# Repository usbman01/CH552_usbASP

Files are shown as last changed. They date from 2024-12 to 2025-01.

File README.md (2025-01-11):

# CH552_usbASP

A CH552 version of the popular usbasp from fischl. The code is mostly based on version 1.8 of nerdralph https://github.com/nerdralph/usbasp with some minor changes, exept for tpi.c and usbdrv.c which are completely new. It will work on the following WCH microcontroller:

  - CH551 (needs some changes because of XDATA limits)
  - CH552
  - CH554

CH552_usbasp is much more stable because it no longer depends on VUSB. On windows machines it can automatically load winusb as driver so no more installation issues and hassles with zadig. If there is already a usbasp installation on the PC with libusb, libusb will be used. On Linux always libusb will be used because WCID is windows only.

## Features:

  - Fullspeed (12MHz) design
  - Firmware update via USB using WCHs WCHISPTool 
  - Automatic driver installation on Win8.1 and above
  - Winusb driver (tested with avrDude >= 7.1)
  - Compound device with USB CDC-ACM serial port 
  - 5V and 3.3V operation

## Config Options:

WCID, TPI, CDC and the fast copy function can be switched off. For details check global.h The code can be compiled using Keil c51, SDCC or Raisonance rc51. A port to IAR EW8051 is still under develpment and currently not working.   
Since i dont have AVRs using TPI at hand TPI is just simulated and may or may not work. 

## Benchmarks:

Since the code is prepared to work with various C compiler it also can be used for benchmarking popular MCS51 C compiler. 

## Limits:

When using the compound version including CDC its neccessary to use avrdude-v8.0-windows-mingw-x64.zip because the normal version can not handle compount devices.

## todo:

 - make usbdrv usb2cv compilant
 - complete CDC support
 - switch to 24MHz fsys so CDC can work up to 115k2 baud
 - complete SDCC support (build) ✔
 - use that extra opcode for memcpy functions ✔
 - add Raisonance RC51 support ✔
 - complete IAR EW8051 support

## References:

 - Datasheet:  https://www.wch-ic.com/downloads/CH552DS1_PDF.html
 - Isptool:    https://www.wchic.com/downloads/WCHISPTool_Setup_exe.html
 - usbasp 1.4: https://www.fischl.de/usbasp/
 - usbasp 1.8: https://github.com/nerdralph/usbasp
 - avrdude:    https://github.com/avrdudes/avrdude/releases

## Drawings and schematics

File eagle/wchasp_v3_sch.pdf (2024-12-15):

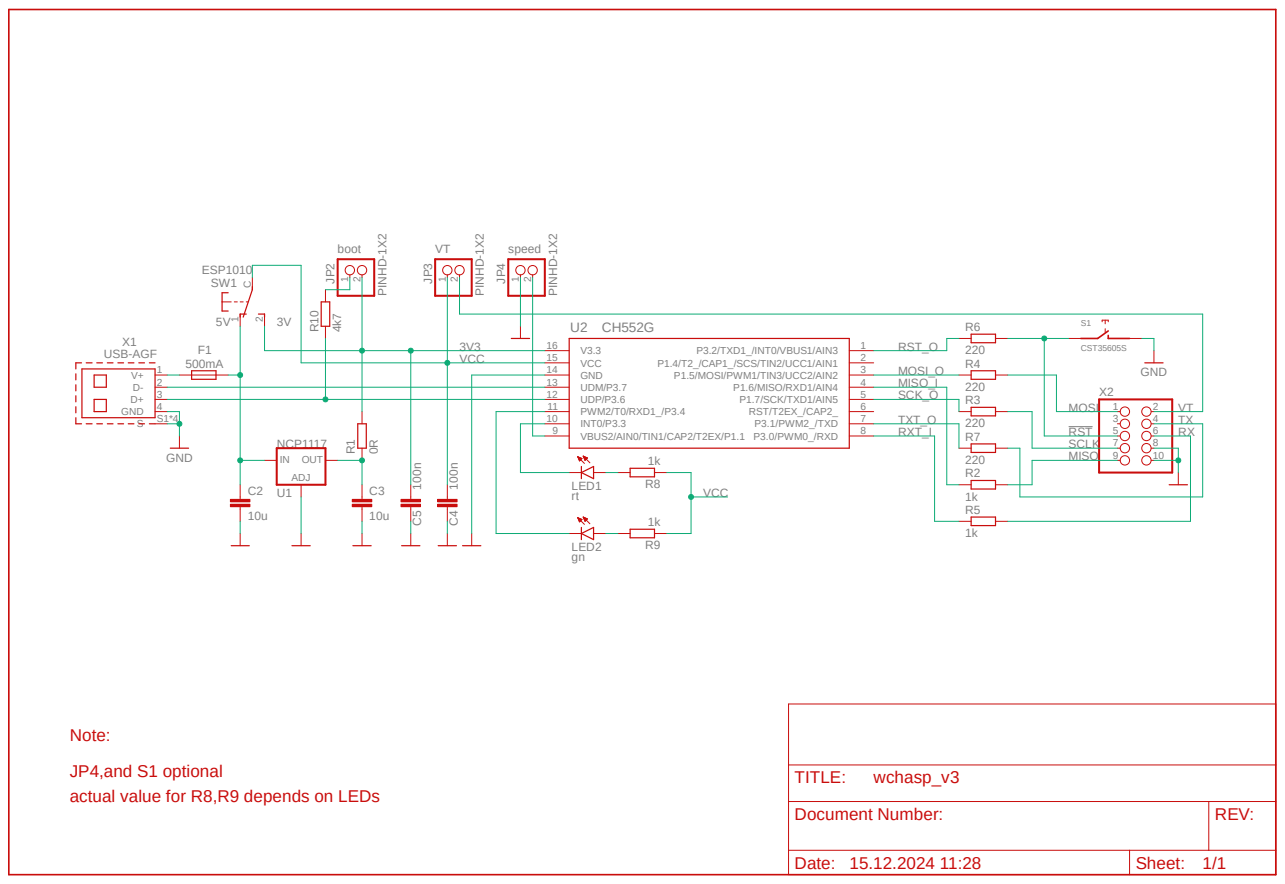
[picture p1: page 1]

JP4,and S1 optional
actual value for R8,R9 depends on LEDs

Document Number: | REV:

Date: 15.12.2024 11:28 | Sheet: 1/1

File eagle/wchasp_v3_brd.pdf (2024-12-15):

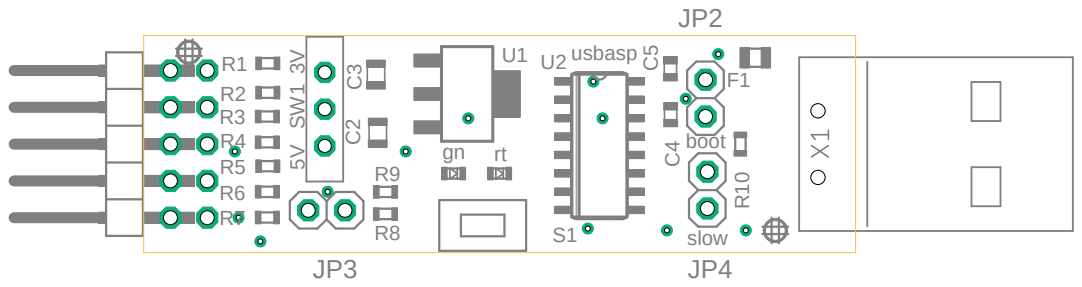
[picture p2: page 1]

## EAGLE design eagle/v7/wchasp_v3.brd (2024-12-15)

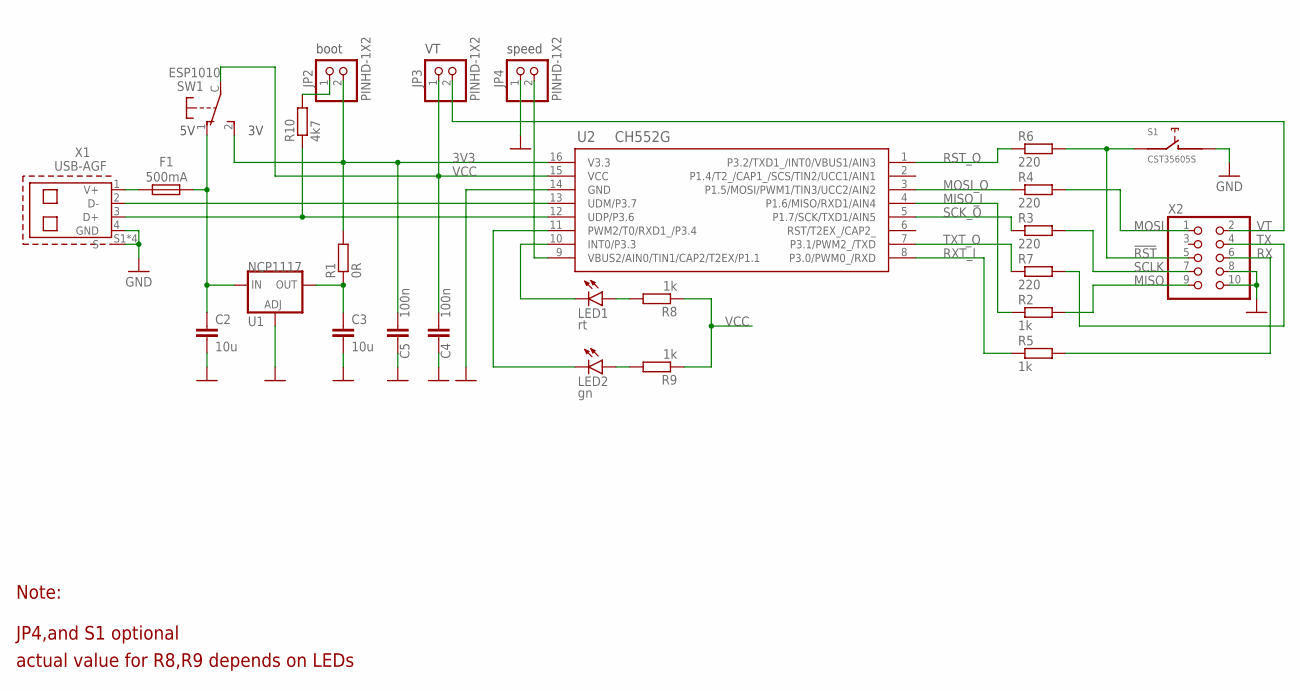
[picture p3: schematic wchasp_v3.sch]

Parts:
C2, C3: 10u; C0805K
C4, C5: 100n; C0603
F1: 500mA; R0805W
JP2, JP3, JP4: PINHD-1X2; 1X2
LED1: rt; D0603
LED2: gn; D0603
R1: 0R; R0603
R2, R5, R8, R9: 1k; R0603
R3, R4, R6, R7: 220; R0603
R10: 4k7; R0603
S1: CST35605S
SW1: ESP1010
U1: NCP1117; SOT223
U2: CH552G; SO16
X1: USB-AGF
X2: PINHD-2X5/90; 2X05/90

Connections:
3V3: C5.1, JP2.2, R1.2, SW1.2 (S), U2.16 (V3.3)
!RST: R6.2, S1.1, X2.5
GND: C2.2, C3.2, C4.2, C5.2, JP4.1, S1.2, U1.1 (ADJ), U2.14 (GND), X1.4 (GND), X1.S1 (S), X1.S2 (S), X1.S3 (S), X1.S4 (S), X2.8, X2.10
MISO: R2.2, X2.9
MISO_I: R2.1, U2.4 (P1.6/MISO/RXD1/AIN4)
MOSI: R4.2, X2.1
MOSI_O: R4.1, U2.3 (P1.5/MOSI/PWM1/TIN3/UCC2/AIN2)
unnamed: JP2.1, R10.2
unnamed: U2.13 (UDM/P3.7), X1.2 (D-)
unnamed: R10.1, U2.12 (UDP/P3.6), X1.3 (D+)
unnamed: LED1.A, R8.2
unnamed: C2.1, F1.2, SW1.1 (O), U1.3 (IN)
unnamed: C3.1, R1.1, U1.2 (OUT), U1.4 (OUT)
unnamed: LED2.A, R9.2
unnamed: LED2.K (C), U2.11 (PWM2/T0/RXD1_/P3.4)
unnamed: LED1.K (C), U2.10 (INT0/P3.3)
unnamed: F1.1, X1.1 (V+)
RST_O: R6.1, U2.1 (P3.2/TXD1_/INT0/VBUS1/AIN3)
RX: R5.2, X2.6
RXT_I: R5.1, U2.8 (P3.0/PWM0_/RXD)
SCK_O: R3.1, U2.5 (P1.7/SCK/TXD1/AIN5)
SCLK: R3.2, X2.7
SLOW: JP4.2, U2.9 (VBUS2/AIN0/TIN1/CAP2/T2EX/P1.1)
TX: R7.2, X2.4
TXT_O: R7.1, U2.7 (P3.1/PWM2_/TXD)
VCC: C4.1, JP3.1, R8.1, R9.1, SW1.C, U2.15 (VCC)
VT: JP3.2, X2.2

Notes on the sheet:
boot
speed
JP4,and S1 optional
actual value for R8,R9 depends on LEDs
Note:

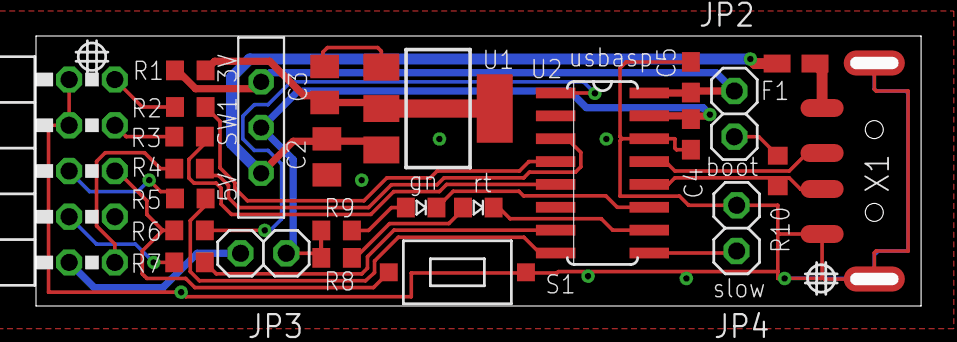
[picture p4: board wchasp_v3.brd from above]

Board: 2 copper layers, 49.2 x 15.0 mm, 28 parts (0 on the bottom side), 27 nets.

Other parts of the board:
U$1, U$2: CENTER

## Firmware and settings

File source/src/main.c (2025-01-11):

/*
 * USBasp - USB in-circuit programmer for Atmel AVR controllers
 *
 * Thomas Fischl <tfischl@gmx.de>
 * 2020 fixes and tweaks by Ralph Doncaster (Nerd Ralph)
 * 2024 usbman (for ch552)
 * License........: GNU GPL v2 (see Readme.txt)
 * Target.........: CH552 @12Mhz
 * Creation Date..: 2005-02-20
 * Last change....: 2020-12-13
 *
 */

#include "..\inc\global.h"
#include "..\inc\usbasp.h"
#include "..\inc\clock.h"

extern uint8_t  UsbConfig;
extern void usbInit(void); 
#ifdef __SDCC_mcs51
  void Usb_IRQ (void) __interrupt (INT_NO_USB);
#endif

void main(void) 
{
    clockInit();
    clockWait(1000 / 32);              // 10ms

 	  SPI_TO_INPUT();
    RST_TO_INPUT();
	
	  usbInit();
	  IE_USB = 1; 
	  EA     = 1;
	  while(UsbConfig ==0) //wait til configured
		{	
			;
		}	

	  LED_GREEN = ON;
    for (;;) 
	  {
       //usbPoll();
    }
}

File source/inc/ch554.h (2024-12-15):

/*
  removed all the typedefs, usb section and C++  
  all names and consts are still the same
*/

#ifndef CH554_H_

#include "compiler.h"

/*  System Registers  */
SFR_(PSW,0xD0);               // program status word
  SBIT_(CY,0xD0,7);           // carry flag
  SBIT_(AC,0xD0,6);           // auxiliary carry flag
  SBIT_(F0,0xD0,5);           // bit addressable general purpose flag 0
  SBIT_(RS1,0xD0,4);          // register R0-R7 bank selection high bit
  SBIT_(RS0,0xD0,3);          // register R0-R7 bank selection low bit
  SBIT_(OV,0xD0,2);           // overflow flag
  SBIT_(F1,0xD0,1);           // bit addressable general purpose flag 1
  SBIT_(P,0xD0,0);            // ReadOnly: parity flag
  #define MASK_PSW_RS 0x18    // bit mask of register R0-R7 bank selection
  // RS1 & RS0: register R0-R7 bank selection
  //    00 - bank 0, R0-R7 @ address 0x00-0x07
  //    01 - bank 1, R0-R7 @ address 0x08-0x0F
  //    10 - bank 2, R0-R7 @ address 0x10-0x17
  //    11 - bank 3, R0-R7 @ address 0x18-0x1F
SFR_(ACC,0xE0);               // accumulator
  SBIT_(ACC7,0xE0,7);
  SBIT_(ACC6,0xE0,6);  
  SBIT_(ACC5,0xE0,5);
  SBIT_(ACC4,0xE0,4);
  SBIT_(ACC3,0xE0,3);
  SBIT_(ACC2,0xE0,2);
  SBIT_(ACC1,0xE0,1);
  SBIT_(ACC0,0xE0,0);
SFR_(B,0xF0);                 // general purpose register B
  SBIT_(B07,0xF0,7);
  SBIT_(B06,0xF0,6);  
  SBIT_(B05,0xF0,5);
  SBIT_(B04,0xF0,4);
  SBIT_(B03,0xF0,3);
  SBIT_(B02,0xF0,2);
  SBIT_(B01,0xF0,1);
  SBIT_(B00,0xF0,0);
SFR_(SP,0x81);                // stack pointer
SFR_(DPL,0x82);               // data pointer low
SFR_(DPH,0x83);               // data pointer high
SFR_(SAFE_MOD,0xA1);          // WriteOnly: writing safe mode
SFR_(CHIP_ID,0xA1);           // ReadOnly: reading chip ID
SFR_(GLOBAL_CFG,0xB1);        // global config, Write@SafeMode
  #define bBOOT_LOAD     0x20 // ReadOnly: boot loader status for discriminating BootLoader or Application: set 1 by power on reset, clear 0 by software reset
  #define bSW_RESET      0x10 // software reset bit, auto clear by hardware
  #define bCODE_WE       0x08 // enable flash-ROM (include code & Data-Flash) being program or erasing: 0=writing protect, 1=enable program and erase
  #define bDATA_WE       0x04 // enable Data-Flash (flash-ROM data area) being program or erasing: 0=writing protect, 1=enable program and erase
  #define bLDO3V3_OFF    0x02 // disable 5V->3.3V LDO: 0=enable LDO for USB and internal oscillator under 5V power, 1=disable LDO, V33 pin input external 3.3V power
  #define bWDOG_EN       0x01 // enable watch-dog reset if watch-dog timer overflow: 0=as timer only, 1=enable reset if timer overflow

/* Clock and Sleep and Power Registers */
SFR_(PCON,0x87);              // power control and reset flag
  #define SMOD           0x80 // baud rate selection for UART0 mode 1/2/3: 0=slow(Fsys/128 @mode2, TF1/32 @mode1/3, no effect for TF2),
                               //   1=fast(Fsys/32 @mode2, TF1/16 @mode1/3, no effect for TF2)
  #define bRST_FLAG1     0x20 // ReadOnly: recent reset flag high bit
  #define bRST_FLAG0     0x10 // ReadOnly: recent reset flag low bit
  #define MASK_RST_FLAG  0x30 // ReadOnly: bit mask of recent reset flag
  #define RST_FLAG_SW    0x00
  #define RST_FLAG_POR   0x10
  #define RST_FLAG_WDOG  0x20
  #define RST_FLAG_PIN   0x30
  #define GF1            0x08 // general purpose flag bit 1
  #define GF0            0x04 // general purpose flag bit 0
  #define PD             0x02 // power-down enable bit, auto clear by wake-up hardware
// bPC_RST_FLAG1 & bPC_RST_FLAG0: recent reset flag
//    00 - software reset, by bSW_RESET=1 @(bBOOT_LOAD=0 or bWDOG_EN=1)
//    01 - power on reset
//    10 - watch-dog timer overflow reset
//    11 - external input manual reset by RST pin

SFR_(CLOCK_CFG,0xB9);          // system clock config: lower 3 bits for system clock Fsys, Write@SafeMode
  #define bOSC_EN_INT     0x80 // internal oscillator enable and original clock selection: 1=enable & select internal clock, 0=disable & select external clock
  #define bOSC_EN_XT      0x40 // external oscillator enable, need quartz crystal or ceramic resonator between XI and XO pins
  #define bWDOG_IF_TO     0x20 // ReadOnly: watch-dog timer overflow interrupt flag, cleared by reload watch-dog count or auto cleared when MCU enter interrupt routine
  #define bROM_CLK_FAST   0x10 // flash-ROM clock frequency selection: 0=normal(for Fosc>=16MHz), 1=fast(for Fosc<16MHz)
  #define bRST            0x08 // ReadOnly: pin RST input
  #define bT2EX_          0x08 // alternate pin for T2EX
  #define bCAP2_          0x08 // alternate pin for CAP2
  #define MASK_SYS_CK_SEL 0x07 // bit mask of system clock Fsys selection
/*
   Fxt = 24MHz(8MHz~25MHz for non-USB application), from external oscillator @XI&XO
   Fosc = bOSC_EN_INT ? 24MHz : Fxt
   Fpll = Fosc * 4 => 96MHz (32MHz~100MHz for non-USB application)
   Fusb4x = Fpll / 2 => 48MHz (Fixed)
              MASK_SYS_CK_SEL[2] [1] [0]
   Fsys = Fpll/3   =  32MHz:  1   1   1
   Fsys = Fpll/4   =  24MHz:  1   1   0
   Fsys = Fpll/6   =  16MHz:  1   0   1
   Fsys = Fpll/8   =  12MHz:  1   0   0
   Fsys = Fpll/16  =   6MHz:  0   1   1
   Fsys = Fpll/32  =   3MHz:  0   1   0
   Fsys = Fpll/128 = 750KHz:  0   0   1
   Fsys = Fpll/512 =187.5KHz: 0   0   0
*/

SFR_(WAKE_CTRL,0xA9);          // wake-up control, Write@SafeMode
  #define bWAK_BY_USB   0x80   // enable wake-up by USB event
  #define bWAK_RXD1_LO  0x40   // enable wake-up by RXD1 low level
  #define bWAK_P1_5_LO  0x20   // enable wake-up by pin P1.5 low level
  #define bWAK_P1_4_LO  0x10   // enable wake-up by pin P1.4 low level
  #define bWAK_P1_3_LO  0x08   // enable wake-up by pin P1.3 low level
  #define bWAK_RST_HI   0x04   // enable wake-up by pin RST high level
  #define bWAK_P3_2E_3L 0x02   // enable wake-up by pin P3.2 (INT0) edge or pin P3.3 (INT1) low level
  #define bWAK_RXD0_LO  0x01   // enable wake-up by RXD0 low level
SFR_(RESET_KEEP,0xFE);         // value keeper during reset
SFR_(WDOG_COUNT,0xFF);         // watch-dog count, count by clock frequency Fsys/65536

/*  Interrupt Registers  */
SFR_(IE,0xA8);                 // interrupt enable
  SBIT_(EA   ,0xA8,7);         // enable global interrupts: 0=disable, 1=enable if E_DIS=0
  SBIT_(E_DIS,0xA8,6);         // disable global interrupts, intend to inhibit interrupt during some flash-ROM operation: 0=enable if EA=1, 1=disable
  SBIT_(ET2  ,0xA8,5);         // enable timer2 interrupt
  SBIT_(ES   ,0xA8,4);         // enable UART0 interrupt
  SBIT_(ET1  ,0xA8,3);         // enable timer1 interrupt
  SBIT_(EX1  ,0xA8,2);         // enable external interrupt INT1
  SBIT_(ET0  ,0xA8,1);         // enable timer0 interrupt
  SBIT_(EX0  ,0xA8,0);         // enable external interrupt INT0
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
